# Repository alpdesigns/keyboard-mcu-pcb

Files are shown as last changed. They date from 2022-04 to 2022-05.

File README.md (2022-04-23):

# keyboard-mcu-pcb

## About

A keyboard MCU PCB that can be connected with the key matrix PCB with a FFC cable. Designed for simplifying routing and removing MLC capacitors from the matrix PCB.

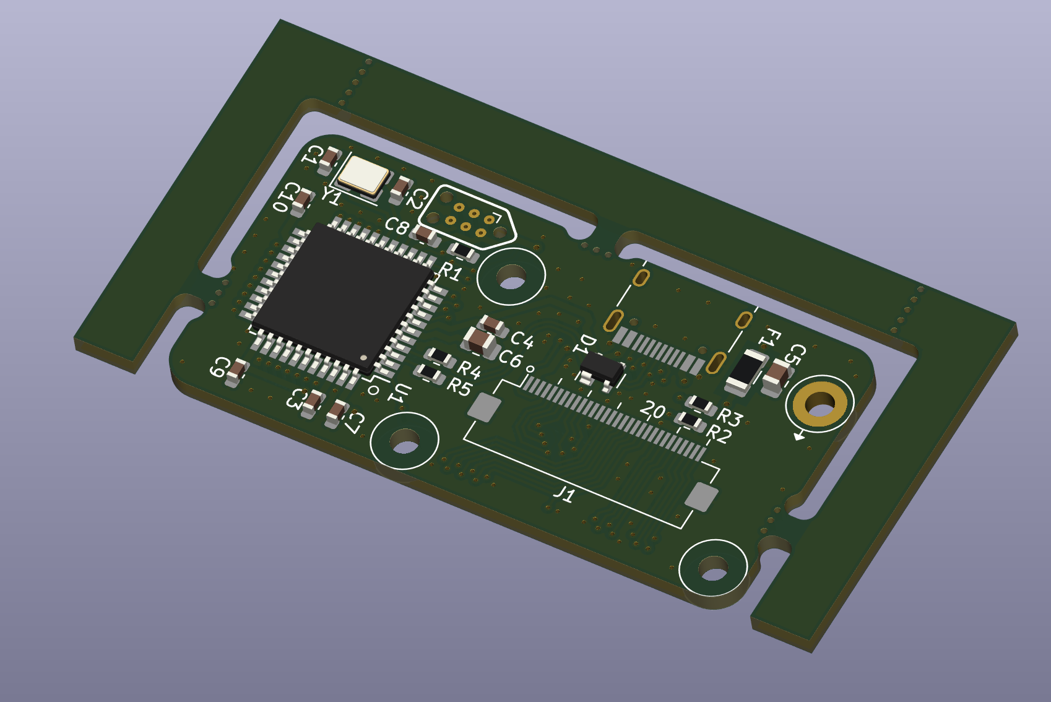
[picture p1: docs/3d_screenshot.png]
3d screenshot


## Features

- Open Source.
- ESD protection diodes.
- Compatible with a 30 pins, 0.5 mm pitch FFC.

## Dimensions

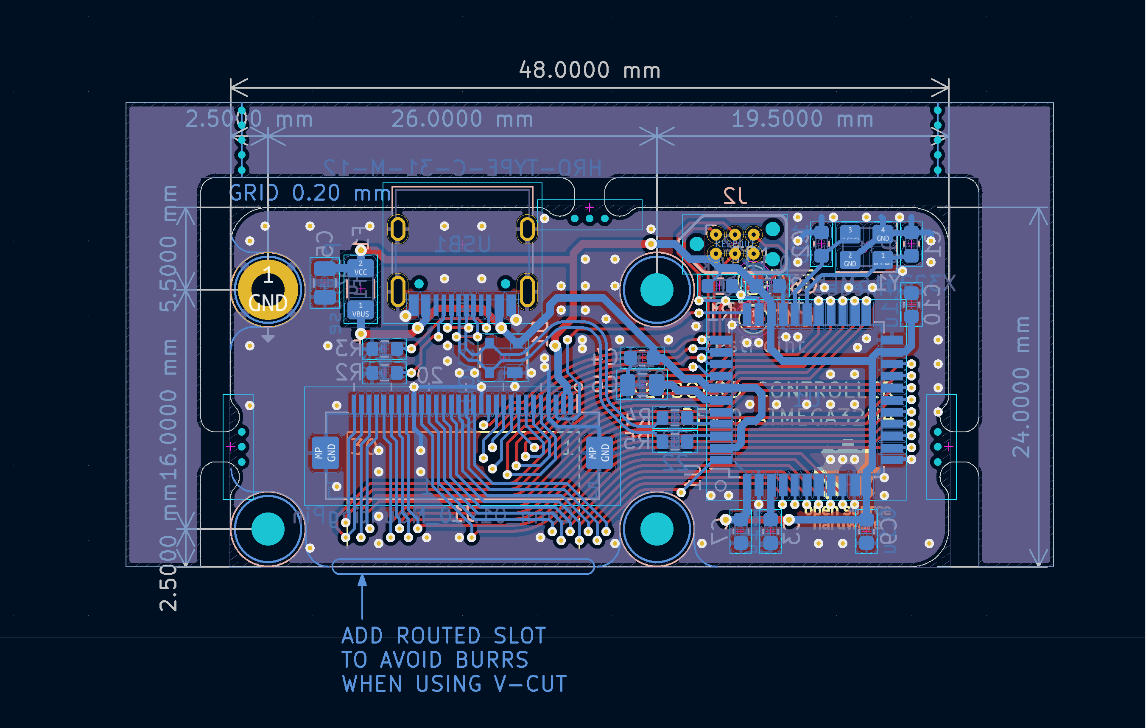
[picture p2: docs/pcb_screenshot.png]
Dimensions


- All holes are M2 clearance hole.
- All corner radii are 2.5 mm.
- PCB thickness is 1.6 mm.

## FFC Wiring

| pins | usage |
|:---|:---|
| 1-2 | Vcc |
| 3 | RGBLED (PWM enabled pin) |
| 4 | GND |
| 5-8 | Interrupt Pins |
| 9-12, 14-21, 23-24 | 14 Cols |
| 25-30 | 6 Rows |

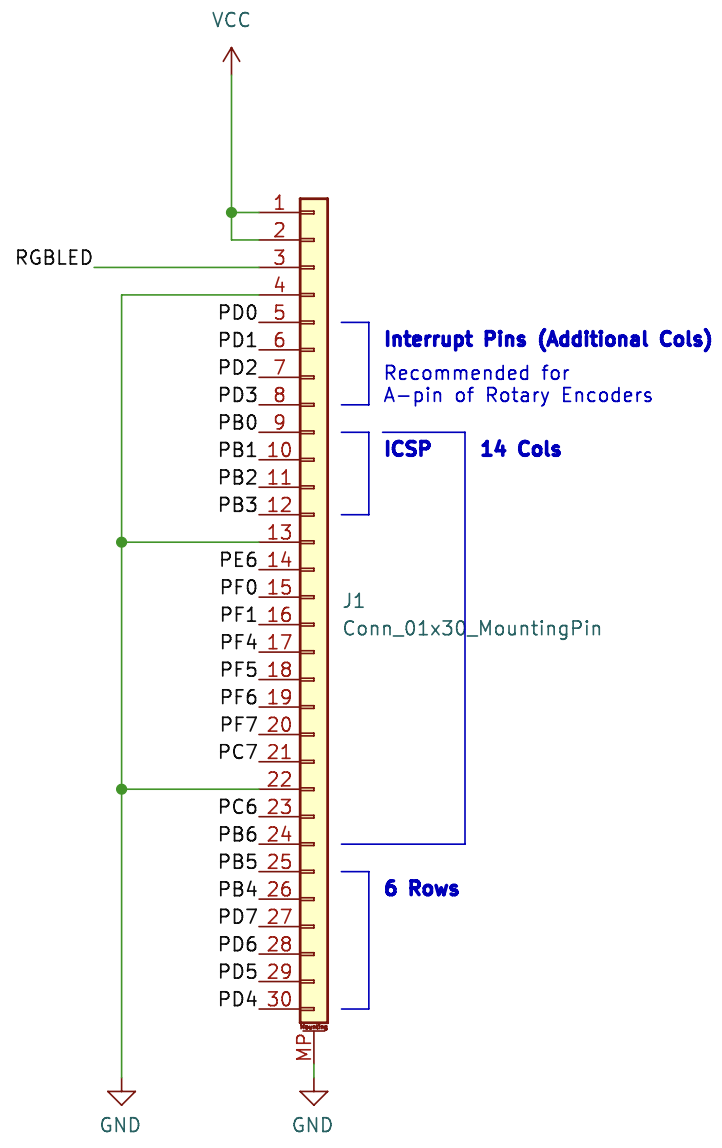
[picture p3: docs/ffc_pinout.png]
FFC Pinout


## License

MIT otherwise noted.

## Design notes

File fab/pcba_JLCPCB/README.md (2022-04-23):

## About

These files are for reference only. Please refer to the instructions from the manufacturer you are in contact with.

## Omitted Parts

ATMEGA32u4-AU is omitted because the price is way more expensive than as usual. Since the MCU is hand solderable, the author highly recommends to solder it by yourself.

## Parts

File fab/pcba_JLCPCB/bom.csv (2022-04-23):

Designator | Comment | Footprint | LCSC
C1, C2, | 10p | Capacitor_SMD:C_0603_1608Metric | C1634
C3, C4, C7, C8, C9, C10, | 0.1u | Capacitor_SMD:C_0603_1608Metric | C14663
C5, C6, | 1u | Capacitor_SMD:C_0805_2012Metric | C28323
D1, | PRTR5V0U2X | Package_TO_SOT_SMD:SOT-143 | C12333
F1, | Polyfuse | Fuse:Fuse_1206_3216Metric | C151162
J1, | Conn_01x30_MountingPin | Connector_FFC-FPC:Hirose_FH12-30S-0.5SH_1x30-1MP_P0.50mm_Horizontal | C506793
R1, | 10k | Resistor_SMD:R_0603_1608Metric | C25804
R2, R3, | 5.1k | Resistor_SMD:R_0603_1608Metric | C23186
R4, R5, | 22 | Resistor_SMD:R_0603_1608Metric | C23345
USB1, | HRO-TYPE-C-31-M-12 | USB_C_Receptacle_USB2.0 | C165948
Y1, | X322516MLB4SI | Crystal:Crystal_SMD_3225-4Pin_3.2x2.5mm | C13738

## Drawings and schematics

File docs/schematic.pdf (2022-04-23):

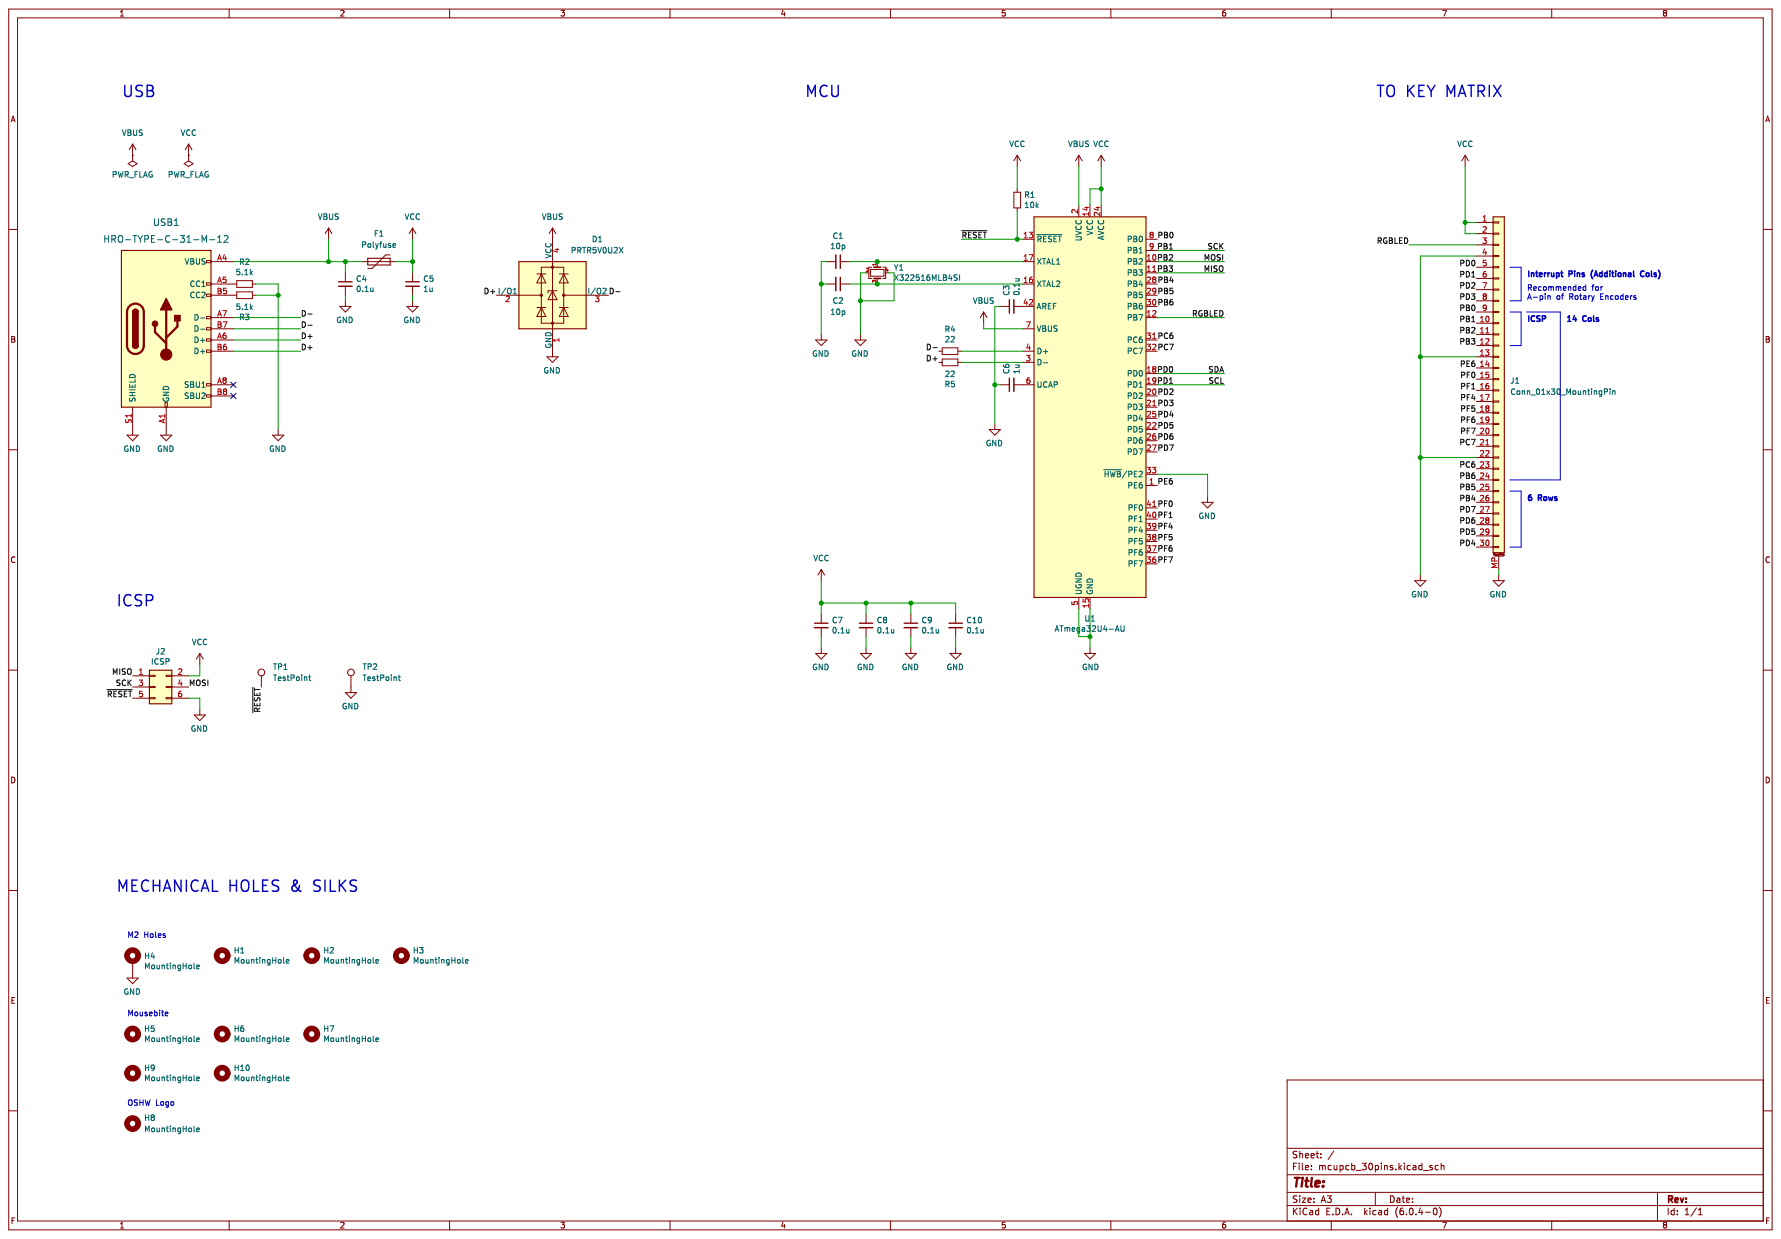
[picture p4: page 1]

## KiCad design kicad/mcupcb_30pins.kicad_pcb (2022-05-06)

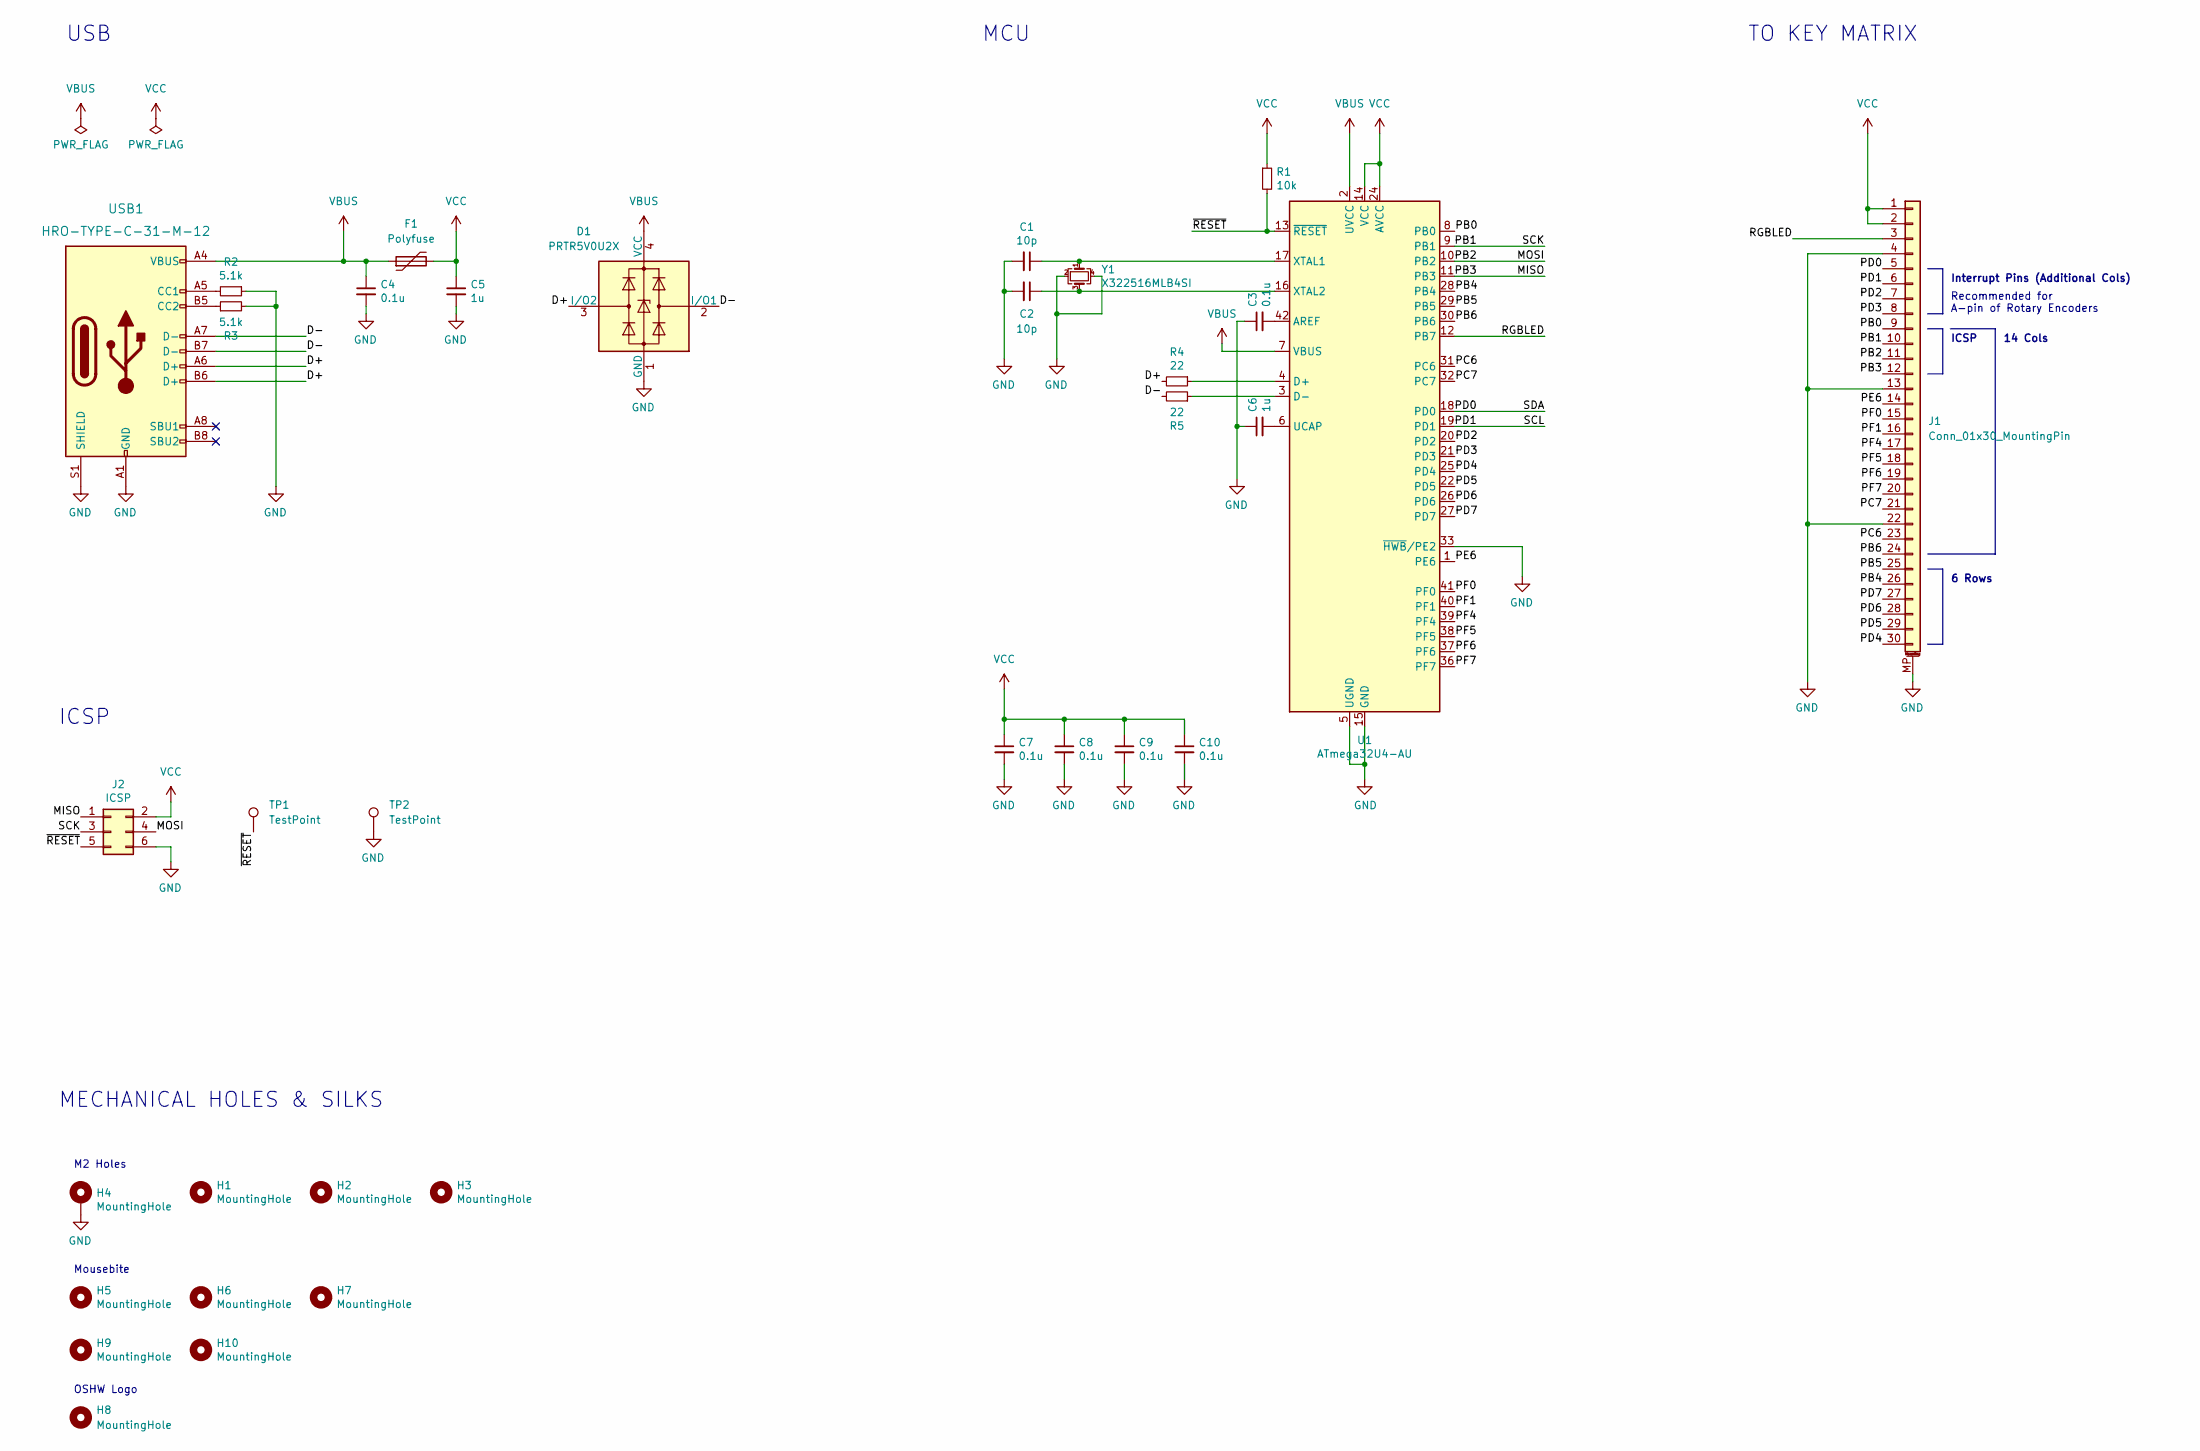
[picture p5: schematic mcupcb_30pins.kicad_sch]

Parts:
C1, C2: 10p; C_0603_1608Metric; LCSC C1634
C3, C4, C7, C8, C9, C10: 0.1u; C_0603_1608Metric; LCSC C14663
C5, C6: 1u; C_0805_2012Metric; LCSC C28323
D1: PRTR5V0U2X; SOT-143; LCSC C12333
F1: Polyfuse; Fuse_1206_3216Metric; LCSC C151162
H1, H2, H3: MountingHole; MountingHole_M2_NoCu; LCSC N/A
H4: MountingHole; MountingHole_M2_PTH; LCSC N/A
H5, H6, H7: MountingHole; Breakaway_small; LCSC N/A
H8: MountingHole; OSHW-Logo_5.7x6mm_SilkScreen; LCSC N/A
H9, H10: MountingHole; Breakaway_panel; LCSC N/A
J1: Conn_01x30_MountingPin; Hirose_FH12-30S-0.5SH_1x30-1MP_P0.50mm_Horizontal; LCSC C506793
J2: ICSP; Tag-Connect_TC2030-IDC-NL_2x03_P1.27mm_Vertical; LCSC N/A
R1: 10k; R_0603_1608Metric; LCSC C25804
R2, R3: 5.1k; R_0603_1608Metric; LCSC C23186
R4, R5: 22; R_0603_1608Metric; LCSC C23345
TP1, TP2: TestPoint; TestPoint_Pad_D1.5mm; LCSC N/A
U1: ATmega32U4-AU; TQFP-44_10x10mm_P0.8mm; LCSC N/A
USB1: HRO-TYPE-C-31-M-12; USB_C_Receptacle_HRO_TYPE-C-31-M-12; LCSC C165948
Y1: X322516MLB4SI; Crystal_SMD_3225-4Pin_3.2x2.5mm; LCSC C13738

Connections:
/D+: D1.3 (I/O2), R4.2, USB1.A6 (D+), USB1.B6 (D+)
/D-: D1.2 (I/O1), R5.2, USB1.A7 (D-), USB1.B7 (D-)
/MISO: J1.12, J2.1, U1.11 (PB3)
/MOSI: J1.11, J2.4, U1.10 (PB2)
/PB0: J1.9, U1.8 (PB0)
/PB1: J1.10, J2.3, U1.9 (PB1)
/PB4: J1.26, U1.28 (PB4)
/PB5: J1.25, U1.29 (PB5)
/PB6: J1.24, U1.30 (PB6)
/PC6: J1.23, U1.31 (PC6)
/PC7: J1.21, U1.32 (PC7)
/PD0: J1.5, U1.18 (PD0)
/PD1: J1.6, U1.19 (PD1)
/PD2: J1.7, U1.20 (PD2)
/PD3: J1.8, U1.21 (PD3)
/PD4: J1.30, U1.25 (PD4)
/PD5: J1.29, U1.22 (PD5)
/PD6: J1.28, U1.26 (PD6)
/PD7: J1.27, U1.27 (PD7)
/PE6: J1.14, U1.1 (PE6)
/PF0: J1.15, U1.41 (PF0)
/PF1: J1.16, U1.40 (PF1)
/PF4: J1.17, U1.39 (PF4)
/PF5: J1.18, U1.38 (PF5)
/PF6: J1.19, U1.37 (PF6)
/PF7: J1.20, U1.36 (PF7)
/RGBLED: J1.3, U1.12 (PB7)
/~RESET: J2.5, R1.2, TP1.1, U1.13 (~RESET)
GND: C1.2, C2.2, C3.1, C4.2, C5.2, C6.1, C7.2, C8.2, C9.2, C10.2, D1.1 (GND), H4.1, J1.4, J1.13, J1.22, J1.MP (MountPin), J2.6, R2.1, R3.2, TP2.1, U1.5 (UGND), U1.15 (GND), U1.23 (GND), U1.33 (~HWB/PE2), U1.35 (GND), U1.43 (GND), USB1.A1 (GND), USB1.A12 (GND), USB1.B1 (GND), USB1.B12 (GND), USB1.S1 (SHIELD), Y1.2, Y1.4
unnamed: C1.1, U1.17 (XTAL1), Y1.1
unnamed: C2.1, U1.16 (XTAL2), Y1.3
unnamed: C3.2, U1.42 (AREF)
unnamed: C6.2, U1.6 (UCAP)
unnamed: R2.2, USB1.A5 (CC1)
unnamed: R3.1, USB1.B5 (CC2)
unnamed: R4.1, U1.4 (D+)
unnamed: R5.1, U1.3 (D-)
VBUS: C4.1, D1.4 (VCC), F1.1, U1.2 (UVCC), U1.7 (VBUS), USB1.A4 (VBUS), USB1.A9 (VBUS), USB1.B4 (VBUS), USB1.B9 (VBUS)
VCC: C5.1, C7.1, C8.1, C9.1, C10.1, F1.2, J1.1, J1.2, J2.2, R1.1, U1.14 (VCC), U1.24 (AVCC), U1.34 (VCC), U1.44 (AVCC)

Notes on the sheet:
ICSP
USB
Mousebite
Recommended for A-pin of Rotary Encoders
M2 Holes
MECHANICAL HOLES & SILKS
OSHW Logo
MCU
Interrupt Pins (Additional Cols)
6 Rows
14 Cols
TO KEY MATRIX

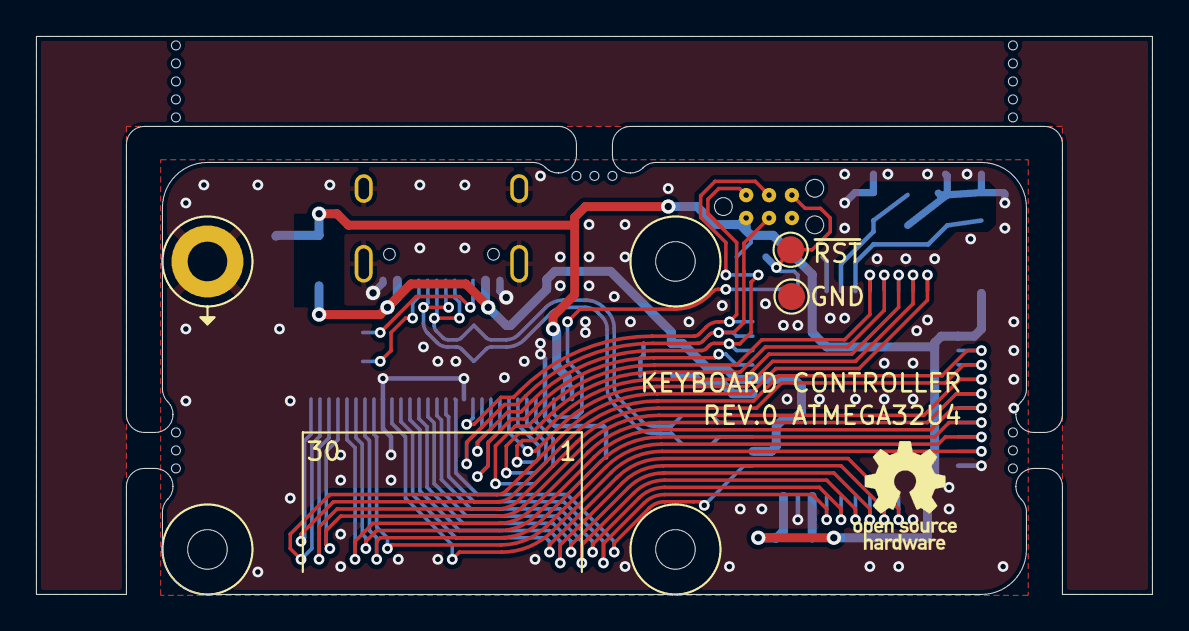
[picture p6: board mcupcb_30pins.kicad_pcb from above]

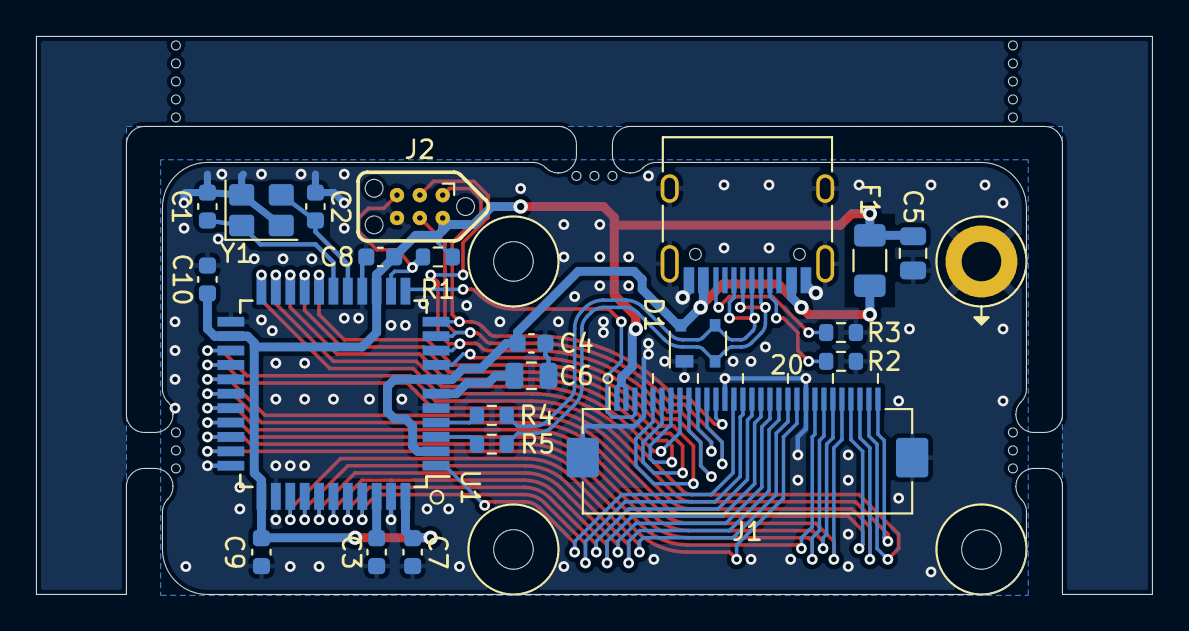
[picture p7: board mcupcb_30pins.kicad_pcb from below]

Board: 2 copper layers, 62.0 x 31.0 mm, 34 parts (26 on the bottom side), 39 nets.
